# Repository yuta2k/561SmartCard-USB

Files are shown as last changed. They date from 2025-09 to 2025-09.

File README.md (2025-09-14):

# 561SmartCard-USB - Smart Card Module to USB Bridge Board

スマートカード (ISO/IEC 7816) 互換モジュールを USB Type-C デバイスとして扱うための基板です。  
USB-スマートカードブリッジ IC 「SEC1110」を採用しており、CCID 準拠のスマートカードリーダとして動作します。

スマートカード互換モジュールは、USB micro-B または DIP (8 ピン) の 2 種類に対応します。  
DIP 形状のものは実物での確認を行っていないため、嵌合・動作しない可能性があります。

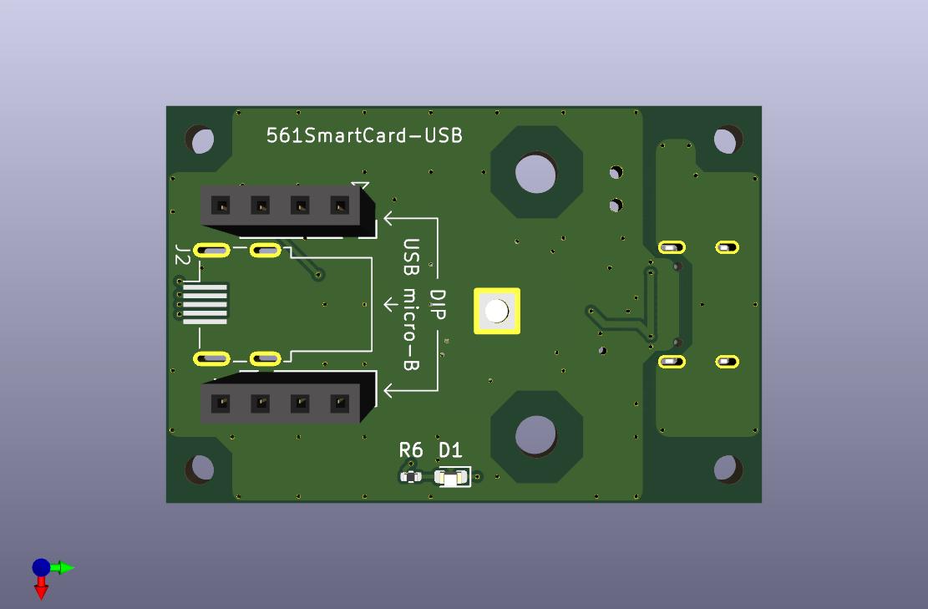
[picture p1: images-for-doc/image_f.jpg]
image_f

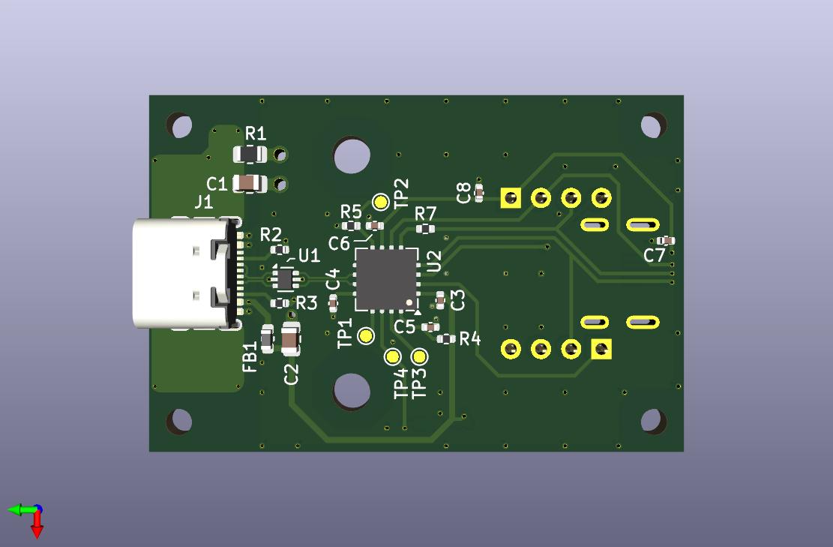
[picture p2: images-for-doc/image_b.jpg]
image_b


## ディレクトリ構成

- kicad - KiCAD 9 プロジェクト
- gerber_jlcpcb - JLCPCB 製造用ガーバ
- bom - 部品表  
  コンデンサ・抵抗等は、定格を満たせば互換品で問題ありません  
  (基本的に 5V を超える耐圧、1/10W 等)
- images-for-doc - 本ドキュメント用の画像

## 対応スマートカード互換モジュールのピンアサイン

### USB micro-B

1. VCC
2. RST_N
3. CLK
4. IO
5. GND

### DIP

△ が 1 番ピンです (見切れていますが、画像 1 枚目右上)。  
ここから反時計周りに 2, 3, ... 8 番ピンとなります。

1. VCC
2. RST_N
3. CLK
4. C4
5. C8
6. IO
7. NC
8. GND

## 備考

- 手実装を前提に SEC1110 (QFP) の Thermal Pad は反対側の面から半田を流し込めるようにしています
- LED はスマートカードアクセス時に点滅します  
  USB ホストに接続しただけでは点灯・点滅しません
- スマートカード互換モジュールのホットプラグには対応していません  
  USB Type-C ケーブルを抜いてからモジュールを抜き差ししてください

## License

MIT License  
See [LICENSE](./LICENSE) for more details.

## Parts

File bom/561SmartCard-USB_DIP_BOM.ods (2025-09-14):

Ref | Category | Manufacture | P/N | F | B | Package | Remarks | Supplier | Footprint
C1 | MLCC | Murata Electronics | GCM21BR72A104KA37 |  | x | 2012 | 0.1u 100V AEC-Q200 |  | Capacitor_SMD:C_0805_2012Metric
C2 | MLCC | Murata Electronics | GRM21BR71A106KA73 |  | x | 2012 | 10u 10V |  | Capacitor_SMD:C_0805_2012Metric
C3 | MLCC | Murata Electronics | GRM155Z71A105KE01 |  | x | 1005 | 1u 10V |  | Capacitor_SMD:C_0402_1005Metric
C4 | MLCC | Murata Electronics | GRM155Z71A105KE01 |  | x | 1005 | 1u 10V |  | Capacitor_SMD:C_0402_1005Metric
C5 | MLCC | Murata Electronics | GRM155R71H104KE14 |  | x | 1005 | 0.1u 50V |  | Capacitor_SMD:C_0402_1005Metric
C6 | MLCC | Murata Electronics | GRM155Z71A105KE01 |  | x | 1005 | 1u 10V |  | Capacitor_SMD:C_0402_1005Metric
C7 | MLCC |  | (DNP) |  | - | 1005 |  |  | Capacitor_SMD:C_0402_1005Metric
C8 | MLCC | Murata Electronics | GRM155R71H104KE14 |  | x | 1005 | 0.1u 50V |  | Capacitor_SMD:C_0402_1005Metric
D1 | LED | Lite-On | LTST-C190GKT | x |  | 1608 |  |  | LED_SMD:LED_0603_1608Metric
FB1 | Ferrite Beads | Murata Electronics | BLM18PG471SN1D |  | x | 1608 | 470ohm@100MHz |  | Inductor_SMD:L_0603_1608Metric
J1 | USB Type-C Receptacle | GCT | USB4105-GF-A |  | x | - |  |  | Connector_USB:USB_C_Receptacle_GCT_USB4105-xx-A_16P_TopMnt_Horizontal
J2 | USB Micro-B Plug |  | (DNP) | - |  | - |  |  | 40-USBSC:USB_Micro-B_Plug_Hirose_ZX60-B-5S(31)
J3 | Pin Header |  | 2.54mm x 4 | x |  | 2.54mm x 4 |  |  | Connector_PinHeader_2.54mm:PinHeader_1x04_P2.54mm_Vertical
J4 | Pin Header |  | 2.54mm x 4 | x |  | 2.54mm x 4 |  |  | Connector_PinHeader_2.54mm:PinHeader_1x04_P2.54mm_Vertical
R1 | Register | KOA | RK73H2ATTD3300F |  | x | 2012 | 330 1% 1/4W |  | Resistor_SMD:R_0805_2012Metric
R2 | Register | KOA | RK73H1ETTP5101F |  | x | 1005 | 5.1k 1% 1/10W |  | Resistor_SMD:R_0402_1005Metric
R3 | Register | KOA | RK73H1ETTP5101F |  | x | 1005 | 5.1k 1% 1/10W |  | Resistor_SMD:R_0402_1005Metric
R4 | Register | KOA | RK73H1ETTP1003F |  | x | 1005 | 100k 1% 1/10W |  | Resistor_SMD:R_0402_1005Metric
R5 | Register – Jumper | Panasonic | ERJ-2GE0R00X |  | x | 1005 | 0 1/10W |  | Resistor_SMD:R_0402_1005Metric
R6 | Register | KOA | RK73H1ETTP6200F | x |  | 1005 | 620 1% 1/10W |  | Resistor_SMD:R_0402_1005Metric
R7 | Register | KOA | RK73H1ETTP33R0F |  | x | 1005 | 33 1% 1/10W |  | Resistor_SMD:R_0402_1005Metric
U1 | TVS Diode Arrays | STMicroelectronics | USBLC6-2P6 |  | x | SOT-666 |  |  | Package_TO_SOT_SMD:SOT-666
U2 | USB-SC Bridge | Microchip | SEC1110-A5-02 |  | x | 16-QFN |  |  | Package_DFN_QFN:QFN-16-1EP_5x5mm_P0.8mm_EP2.7x2.7mm

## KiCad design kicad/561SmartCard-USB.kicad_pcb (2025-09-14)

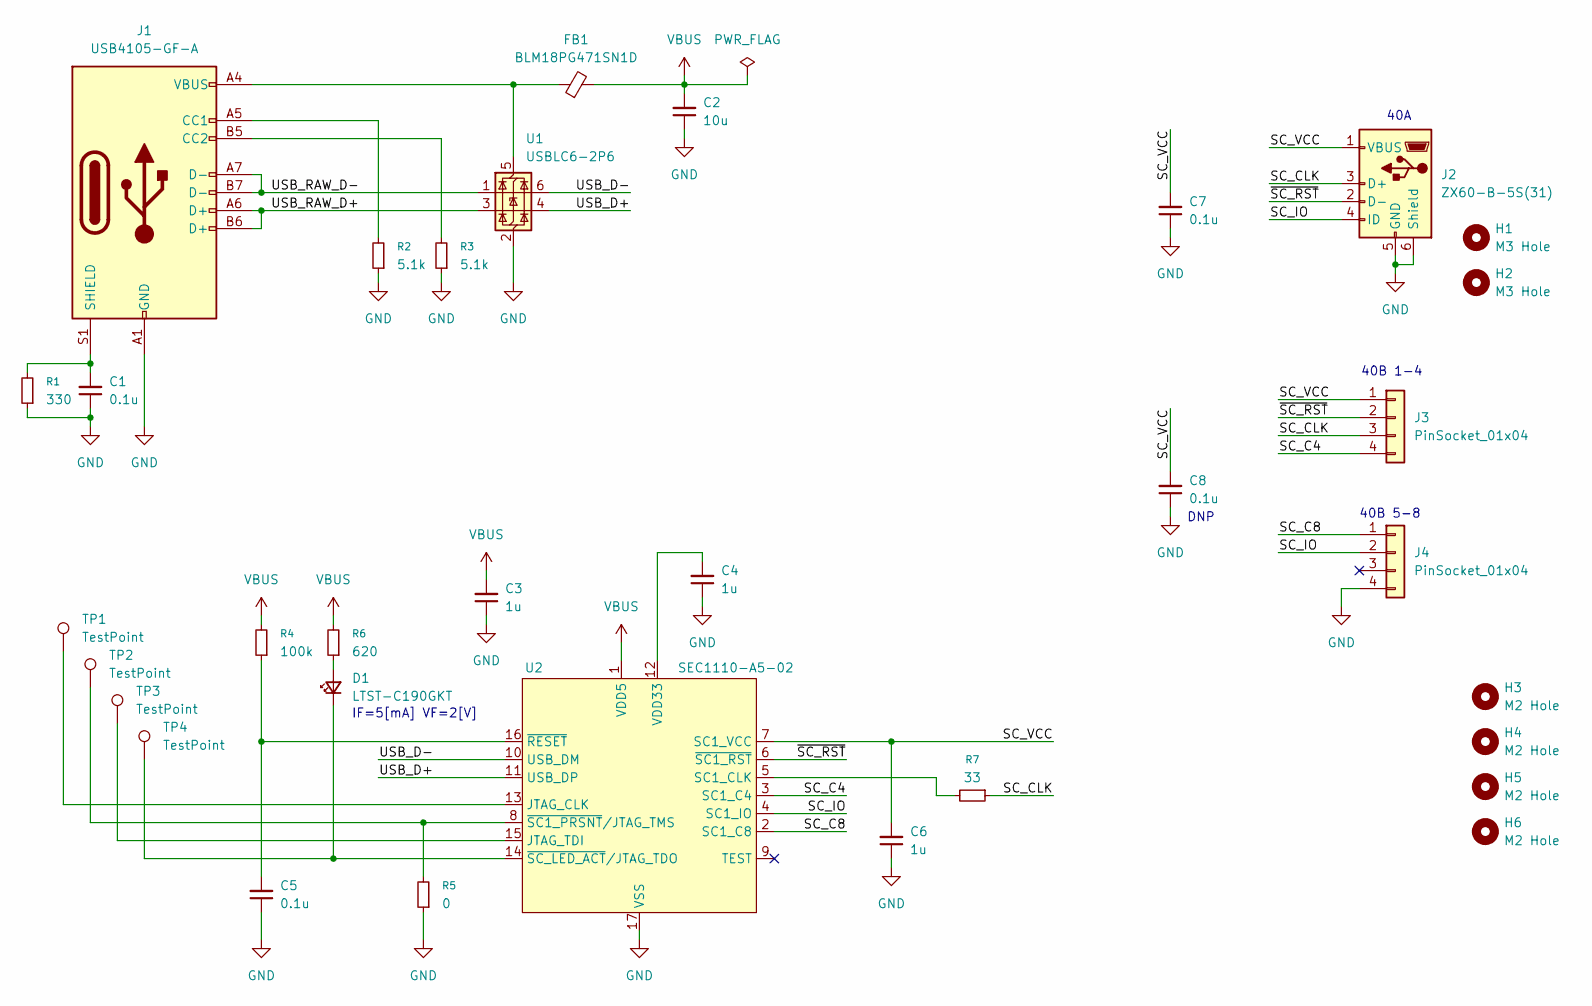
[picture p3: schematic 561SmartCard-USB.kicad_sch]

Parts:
C1: 0.1u; C_0805_2012Metric
C2: 10u; C_0805_2012Metric
C3, C4, C6: 1u; C_0402_1005Metric
C5, C7, C8: 0.1u; C_0402_1005Metric
D1: LTST-C190GKT; LED_0603_1608Metric
FB1: BLM18PG471SN1D; L_0603_1608Metric
H1, H2: M3 Hole; MountingHole_3.2mm_M3
H3, H4, H5, H6: M2 Hole; MountingHole_2.2mm_M2
J1: USB4105-GF-A; USB_C_Receptacle_GCT_USB4105-xx-A_16P_TopMnt_Horizontal
J2: ZX60-B-5S(31); USB_Micro-B_Plug_Hirose_ZX60-B-5S(31)
J3, J4: PinSocket_01x04; PinSocket_1x04_P2.54mm_Vertical
R1: 330; R_0805_2012Metric
R2, R3: 5.1k; R_0402_1005Metric
R4: 100k; R_0402_1005Metric
R5: 0; R_0402_1005Metric
R6: 620; R_0402_1005Metric
R7: 33; R_0402_1005Metric
TP1, TP2, TP3, TP4: TestPoint; TestPoint_Pad_D1.0mm
U1: USBLC6-2P6; SOT-666
U2: SEC1110-A5-02; QFN-16-1EP_5x5mm_P0.8mm_EP2.7x2.7mm

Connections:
/SC_C4: J3.4, U2.3 (SC1_C4)
/SC_C8: J4.1, U2.2 (SC1_C8)
/SC_CLK: J2.3 (D+), J3.3, R7.1
/SC_IO: J2.4 (ID), J4.2, U2.4 (SC1_IO)
/SC_VCC: C6.2, C7.2, C8.2, J2.1 (VBUS), J3.1, U2.7 (SC1_VCC)
/USB_D+: U1.4 (I/O2), U2.11 (USB_DP)
/USB_D-: U1.6 (I/O1), U2.10 (USB_DM)
/USB_RAW_D+: J1.A6 (D+), J1.B6 (D+), U1.3 (I/O2)
/USB_RAW_D-: J1.A7 (D-), J1.B7 (D-), U1.1 (I/O1)
/~SC_RST: J2.2 (D-), J3.2, U2.6 (~SC1_RST)
GND: C1.1, C2.1, C3.1, C4.1, C5.1, C6.1, C7.1, C8.1, J1.A1 (GND), J1.A12 (GND), J1.B1 (GND), J1.B12 (GND), J2.5 (GND), J2.6 (Shield), J4.4, R1.1, R2.1, R3.1, R5.1, U1.2 (GND), U2.17 (VSS)
unnamed: D1.2 (A), R6.1
unnamed: D1.1 (K), TP4.1, U2.14 (~SC_LED_ACT/JTAG_TDO)
unnamed: J1.A5 (CC1), R2.2
unnamed: J1.B5 (CC2), R3.2
unnamed: C1.2, J1.S1 (SHIELD), R1.2
unnamed: FB1.1, J1.A4 (VBUS), J1.A9 (VBUS), J1.B4 (VBUS), J1.B9 (VBUS), U1.5 (VBUS)
unnamed: TP1.1, U2.13 (JTAG_CLK)
unnamed: TP3.1, U2.15 (JTAG_TDI)
unnamed: R7.2, U2.5 (SC1_CLK)
unnamed: C4.2, U2.12 (VDD33)
unnamed: C5.2, R4.1, U2.16 (~RESET)
unnamed: R5.2, TP2.1, U2.8 (~SC1_PRSNT/JTAG_TMS)
VBUS: C2.2, C3.2, FB1.2, R4.2, R6.2, U2.1 (VDD5)

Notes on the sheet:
DNP
40A
IF=5[mA] VF=2[V]
40B 5-8
40B 1-4

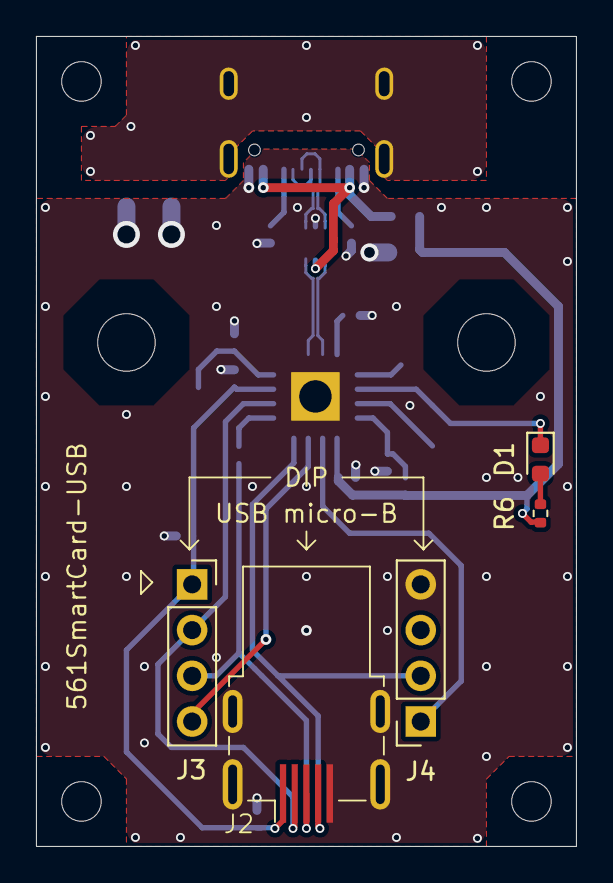
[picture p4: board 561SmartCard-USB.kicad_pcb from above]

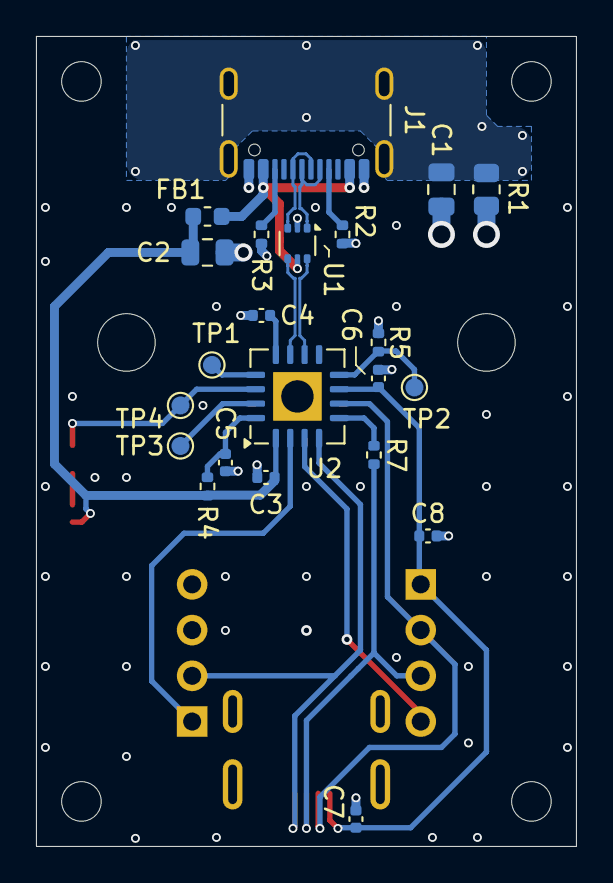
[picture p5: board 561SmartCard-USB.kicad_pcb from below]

Board: 4 copper layers, 30.0 x 45.0 mm, 33 parts (22 on the bottom side), 24 nets.

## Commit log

2025-09-14 基板設計・製造用データを追加
    [561SmartCard-USB-B_Cu.gbl, 561SmartCard-USB-B_Mask.gbs, 561SmartCard-USB-B_Paste.gbp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]
2025-09-14 README.md 更新
